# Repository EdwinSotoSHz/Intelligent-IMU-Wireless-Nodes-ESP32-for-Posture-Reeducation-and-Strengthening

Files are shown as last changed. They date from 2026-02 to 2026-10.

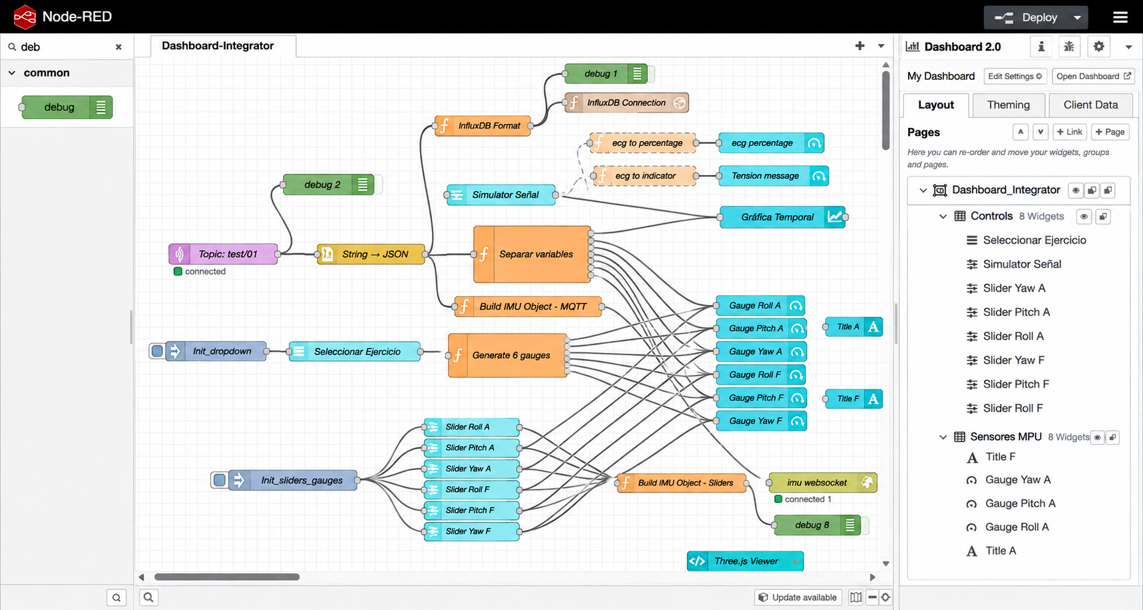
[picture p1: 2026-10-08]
docs/assets/img/nodered_panel.png

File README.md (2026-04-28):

<div align="center">










</div>

# RehabiNodes

> Sistema de monitoreo inalámbrico basado en sensores y tecnologías open source que, al combinar unidades de medición inercial (IMU) y sensores de electromiografía/ECG, es capaz de capturar, procesar y visualizar en tiempo real el movimiento y la actividad muscular del brazo y antebrazo, con el propósito de mejorar la precisión en la ejecución de ejercicios y optimizar los procesos de rehabilitación física domiciliaria.

---

## 📖 Descripción

**RehabiNodes** es un prototipo de plataforma de rehabilitación física domiciliaria orientada a la recuperación funcional del brazo y antebrazo tras una lesión.

El sistema integra dos fuentes de datos complementarias:

- **Nodos IMU inalámbricos** (ESP32 + MPU9250) que miden la orientación y el movimiento en los 3 ejes del brazo y el antebrazo, permitiendo evaluar el rango articular y la calidad de ejecución de cada ejercicio.
- **Sensor ECG/EMG** (AD8232) embebido en el nodo de brazo, que captura la señal eléctrica muscular para detectar compensaciones, fatiga y nivel de activación durante la sesión.

Toda la información se visualiza en tiempo real a través de un panel centralizado (Node Red) que incluye un **modelo 3D interactivo simple** del brazo (Three.js), **estimación de ángulos y compensaciones por visión artificial** (MediaPipe), y **gráficas históricas de señales** (Grafana + InfluxDB).

---

## 🎯 Objetivo

Diseñar e implementar un sistema portátil e inalámbrico para la medición y análisis del movimiento del brazo y antebrazo, con el fin de:

- Guiar al paciente durante ejercicios de **movilidad motora**, **rango articular** y **estiramiento**.
- Apoyar la **readaptación progresiva y segura** después de una lesión, reintegrando al paciente a sus rutinas de forma controlada.
- Visualizar **compensaciones posturales** y movimientos inadecuados mediante estimación de ángulos y posición.
- Proporcionar al clínico **métricas** (rango de movimiento, actividad muscular, simetría) para el seguimiento terapéutico.

### Metas técnicas

- **Hardware sensorial:** Integrar y calibrar IMUs (MPU9250) en nodos de brazo y antebrazo para capturar ángulos de rotación y aceleración en 3 ejes.
- **Procesamiento de señales:** Filtrar y procesar datos brutos de sensores para interpretar movimientos y detectar compensaciones musculares inadecuadas.
- **Interfaz de usuario (Dashboard):** Desarrollar un panel en Node-RED con visualización en tiempo real (Three.js + MediaPipe) y seguimiento histórico (Grafana + InfluxDB).

---

## 🔬 Alcance del Prototipo

Este prototipo se centra exclusivamente en la rehabilitación del **brazo y antebrazo**. Las capacidades actuales son:

<table border="1" cellspacing="0" cellpadding="6">
  <thead>
    <tr>
      <th>Capacidad</th>
      <th>Implementación</th>
    </tr>
  </thead>
  <tbody>
    <tr>
      <td>Medición de movimiento en 3 ejes</td>
      <td>IMU MPU9250 en nodo de brazo y antebrazo</td>
    </tr>
    <tr>
      <td>Señal ECG / actividad muscular</td>
      <td>AD8232 en nodo de brazo</td>
    </tr>
    <tr>
      <td>Estimación de movimientos articulares</td>
      <td>Visualización de landmarks de MediaPipe</td>
    </tr>
    <tr>
      <td>Apoyo visual para la identificación de compensaciones</td>
      <td>MediaPipe y cálculo de ángulos</td>
    </tr>
    <tr>
      <td>Visualización 3D simple en tiempo real</td>
      <td>Three.js actualizado por WebSocket</td>
    </tr>
    <tr>
      <td>Almacenamiento y análisis histórico</td>
      <td>InfluxDB + Grafana</td>
    </tr>
    <tr>
      <td>Panel de control clínico</td>
      <td>Node-RED con iframes al servidor Node.js</td>
    </tr>
    <tr>
      <td>Comunicación inalámbrica de largo alcance</td>
      <td>ESP-NOW + LoRa + GPRS/4G + MQTT</td>
    </tr>
  </tbody>
</table>

> ⚠️ El análisis de postura corporal completa (cuerpo, cadera, rodillas y manos) **es compleentario** de este prototipo y podrá escalarse en versiones futuras.

---

## 🏗️ Arquitectura del Sistema y Flujo de Datos

```mermaid

graph LR
    %% ===== ESTILOS BASADOS EN LOGOS OFICIALES (Borde fuerte / Fondo suave) =====
    classDef hardware fill:#f5f5f5,stroke:#9e9e9e,stroke-width:2px,color:#212121
    classDef master fill:#e3f2fd,stroke:#2196f3,stroke-width:2px,color:#0d47a1
    classDef gateway fill:#e8f5e9,stroke:#4caf50,stroke-width:2px,color:#1b5e20
    classDef cloud fill:#ede7f6,stroke:#673ab7,stroke-width:2px,color:#311b92
    classDef docker fill:#e1f5fe,stroke:#0db7ed,stroke-width:2px,color:#006064
    classDef nodered fill:#ffebee,stroke:#8f0000,stroke-width:2px,color:#8f0000
    classDef influx fill:#e1f5fe,stroke:#00a3e0,stroke-width:2px,color:#003d5b
    classDef grafana fill:#fff3e0,stroke:#f05a28,stroke-width:2px,color:#bf360c
    classDef nodejs fill:#f1f8e9,stroke:#68a063,stroke-width:2px,color:#1b5e20

    subgraph Perifericos ["Nodos Sensores"]
        A1["💪 <b>Arm Node</b><br/>ESP32-C3 + MPU9250 + AD8232"]
        A2["💪 <b>Forearm Node</b><br/>ESP32-C3 + MPU9250"]
    end

    B1["🧠 <b>Master Node</b><br/>ESP32 + LoRa SX1278"]
    
    C1["📡 <b>Gateway</b><br/>LILYGO T70g"]

    D1{{"☁️ <b>EMQX MQTT Broker</b>"}}

    subgraph DockerContainer ["🐋 Docker Compose"]
        E1["📉 <b>Node-RED</b>"]
        E2[("🗄️ InfluxDB")]
        E3["📈 <b>Grafana</b>"]
        
        subgraph NodeJS ["⚙️ Servidor Node.js"]
            E4["📷 MediaPipe<br/>(Pose Estimation)"]
            E5["🧊 Three.js<br/>(3D Render)"]
        end
    end

    %% Conexiones y Protocolos
    A1 & A2 -- "ESP-NOW" --> B1
    B1 -- "LoRa" --> C1
    C1 -- "GPRS/4G LTE" --> D1
    D1 --> E1
    
    %% Conexiones de visualización e integración
    E1 -- "iframe" --> E5
    E1 -- "iframe" --> E4
    E1 <-->|"WebSocket"| E5
    E1 -->|"Flux"| E2
    E2 -->|"Flux"| E3

    %% Aplicación de Estilos
    class A1,A2 hardware
    class B1 master
    class C1 gateway
    class D1 cloud
    class DockerContainer docker
    class E1 nodered
    class E2 influx
    class E3 grafana
    class E4,E5 nodejs
    
```

<table border="1" cellspacing="0" cellpadding="8">
  <thead>
    <tr>
      <th>Componente</th>
      <th>Rol funcional en el flujo</th>
    </tr>
  </thead>
  <tbody>
    <tr>
      <td><strong>node_arm</strong><br/><small>ESP32-C3 + MPU9250 + AD8232</small></td>
      <td>Captura IMU (orientación) y ECG del brazo. Transmite por ESP‑NOW al maestro.</td>
    </tr>
    <tr>
      <td><strong>node_forearm</strong><br/><small>ESP32-C3 + GY‑91 (MPU9250 + BMP280)</small></td>
      <td>Captura IMU del antebrazo. Transmite por ESP‑NOW al maestro. (BMP280 no usado activamente)</td>
    </tr>
    <tr>
      <td><strong>master_node</strong><br/><small>ESP32 + LoRa Ra‑02 SX1278</small></td>
      <td>Agrega datos de ambos nodos vía ESP‑NOW y los retransmite por LoRa hacia el gateway.</td>
    </tr>
    <tr>
      <td><strong>gateway</strong><br/><small>LILYGO T‑SIM7070G + LoRa</small></td>
      <td>Recibe el paquete LoRa y lo publica al broker MQTT usando GPRS/4G LTE.</td>
    </tr>
    <tr>
      <td><strong>Broker MQTT (EMQX)</strong></td>
      <td>Punto de entrada único al backend. Desacopla la capa de hardware del procesamiento.</td>
    </tr>
    <tr>
      <td><strong>Node‑RED</strong></td>
      <td>Hub de integración: suscribe MQTT, normaliza datos, los envía a InfluxDB y al servidor web (vía WebSocket/HTTP).</td>
    </tr>
    <tr>
      <td><strong>ExpressJS (servidor Node.js)</strong></td>
      <td>Sirve las interfaces de MediaPipe y Three.js. Gestiona el WebSocket que actualiza el modelo 3D.</td>
    </tr>
    <tr>
      <td><strong>Three.js</strong></td>
      <td>Renderiza el modelo 3D del brazo/antebrazo en el navegador, actualizado en tiempo real por WebSocket.</td>
    </tr>
    <tr>
      <td><strong>MediaPipe JS</strong></td>
      <td>Estima ángulos articulares y detecta compensaciones motoras mediante visión por computadora (landmarks).</td>
    </tr>
    <tr>
      <td><strong>InfluxDB</strong></td>
      <td>Almacena series temporales de IMU y ECG para análisis histórico y trazabilidad de sesiones.</td>
    </tr>
    <tr>
      <td><strong>Grafana</strong></td>
      <td>Dashboards de evolución clínica: rangos de movimiento, actividad muscular, simetría, alertas.</td>
    </tr>
  </tbody>
</table>

---

## 📡 Protocolos de Comunicación

<table>
  <thead>
    <tr>
      <th>Protocolo</th>
      <th>Función en el proyecto</th>
      <th>Descripción breve</th>
    </tr>
  </thead>
  <tbody>
    <tr>
      <td><strong>ESP-NOW</strong></td>
      <td>Comunicación entre nodos (brazo/antebrazo) y nodo maestro</td>
      <td>Protocolo peer-to-peer sin conexión WiFi de Espressif, baja latencia</td>
    </tr>
    <tr>
      <td><strong>LoRa (SX1278)</strong></td>
      <td>Enlace inalámbrico nodo maestro → gateway</td>
      <td>Modulación de espectro ensanchado para largo alcance y bajo consumo</td>
    </tr>
    <tr>
      <td><strong>GPRS / 4G LTE</strong></td>
      <td>Gateway → Broker MQTT (transmisión celular)</td>
      <td>Red móvil de datos para enviar información a la nube</td>
    </tr>
    <tr>
      <td><strong>MQTT</strong></td>
      <td>Broker ↔ Node-RED y publicaciones desde gateway/mocks</td>
      <td>Protocolo ligero de publicación/suscripción sobre TCP/IP</td>
    </tr>
    <tr>
      <td><strong>WebSocket</strong></td>
      <td>Servidor ExpressJS ↔ Three.js (modelo 3D)</td>
      <td>Canal bidireccional full-duplex sobre una única conexión TCP</td>
    </tr>
    <tr>
      <td><strong>HTTP / HTTPS</strong></td>
      <td>Servidor ExpressJS entrega archivos estáticos y rutas REST</td>
      <td>Protocolo cliente-servidor para transferencia de hipertexto</td>
    </tr>
    <tr>
      <td><strong>I²C (I2C)</strong></td>
      <td>Comunicación ESP32-C3 ↔ MPU9250 y ESP32-C3 ↔ AD8232</td>
      <td>Bus serie síncrono de dos hilos (SDA/SCL) para sensores</td>
    </tr>
    <tr>
      <td><strong>SPI</strong></td>
      <td>ESP32 ↔ Módulo LoRa SX1278 (nodo maestro)</td>
      <td>Bus serie síncrono full-duplex con selección de esclavo</td>
    </tr>
    <tr>
      <td><strong>UART (Serial)</strong></td>
      <td>Depuración (Serial Monitor) y posible comunicación entre módulos</td>
      <td>Comunicación asíncrona simple con TX/RX</td>
    </tr>
    <tr>
      <td><strong>USB (CDC)</strong></td>
      <td>Carga de firmware y monitoreo serial en ESP32-C3/ESP32</td>
      <td>USB nativo o serial-over-USB para programación y debug</td>
    </tr>
  </tbody>
</table>

### Hardware de Sensado y Adquisición

<table>
  <thead>
    <tr>
      <th>Componente</th>
      <th>Rol</th>
      <th>Notas</th>
    </tr>
  </thead>
  <tbody>
    <tr>
      <td><strong>ESP32-C3 Super Mini</strong></td>
      <td>MCU de los nodos de brazo y antebrazo</td>
      <td>Bajo consumo, formato compacto</td>
    </tr>
    <tr>
      <td><strong>ESP32</strong></td>
      <td>MCU del nodo maestro</td>
      <td>Mayor cantidad de pines para LoRa y periféricos</td>
    </tr>
    <tr>
      <td><strong>LILYGO T-SIM7070G</strong></td>
      <td>Gateway con conectividad celular</td>
      <td>GPRS/4G LTE integrado + interfaz para LoRa</td>
    </tr>
    <tr>
      <td><strong>MPU9250</strong></td>
      <td>IMU 9-DOF (brazo)</td>
      <td>Acelerómetro + giroscopio + magnetómetro</td>
    </tr>
    <tr>
      <td><strong>MPU9250</strong></td>
      <td>IMU + barómetro (antebrazo)</td>
      <td>Integra MPU9250 y BMP280 (altitud/temperatura)</td>
    </tr>
    <tr>
      <td><strong>AD8232</strong></td>
      <td>Sensor ECG / EMG (brazo)</td>
      <td>Captura de señal eléctrica muscular</td>
    </tr>
    <tr>
      <td><strong>Ra-02 SX1278</strong></td>
      <td>Módulo LoRa</td>
      <td>Enlace nodo maestro ↔ gateway. Bajo consumo, largo alcance</td>
    </tr>
  </tbody>
</table>

### Backend e Infraestructura

<table>
  <thead>
    <tr>
      <th>Tecnología</th>
      <th>Rol</th>
    </tr>
  </thead>
  <tbody>
    <tr>
      <td><strong>Node.js + ExpressJS</strong></td>
      <td>Servidor HTTP, WebSocket y archivos estáticos</td>
    </tr>
    <tr>
      <td><strong>InfluxDB</strong></td>
      <td>Base de datos de series temporales (IMU, ECG)</td>
    </tr>
    <tr>
      <td><strong>Docker + Docker Compose</strong></td>
      <td>Contenerización de todo el stack</td>
    </tr>
  </tbody>
</table>

### Visualización en Tiempo Real

<table>
  <thead>
    <tr>
      <th>Tecnología</th>
      <th>Rol</th>
    </tr>
  </thead>
  <tbody>
    <tr>
      <td><strong>Node-RED</strong></td>
      <td>Dashboard principal, integración MQTT, iframes y WebSocket</td>
    </tr>
    <tr>
      <td><strong>Three.js</strong></td>
      <td>Modelo 3D del brazo/antebrazo actualizado por WebSocket</td>
    </tr>
    <tr>
      <td><strong>MediaPipe JS</strong></td>
      <td>Estimación de ángulos articulares y detección de compensaciones por cámara</td>
    </tr>
    <tr>
      <td><strong>Grafana</strong></td>
      <td>Dashboards históricos y alertas clínicas</td>
    </tr>
  </tbody>
</table>

> [!NOTE]  
> Todas las tecnologías listadas son **open source** o con **licencia de uso libre**.

---

## 📁 Estructura del Repositorio

```bash
📁 RehabiNodes/
├── 📁 3D-Model/           # Modelos STL de carcasas para impresión 3D
├── 📁 Project/            # Desarrollo completo del sistema
│   ├── 📁 IoT/            # Firmware ESP32 (nodos, gateway y maestro)
│   ├── 📁 webservices/    # Backend Node.js + visualización (Three.js, MediaPipe)
│   ├── 📁 mocks/          # Simulación de datos sin hardware físico
│   └── 📁 Dashboard/      # Exportaciones de dashboards (Node-RED / Grafana / InfluxDB)
├── 📁 Tests/              # Pruebas y experimentación por subsistema
├── 📁 Wiring-Diagrams/    # Diagramas eléctricos y de conexión
├── 📁 Releases/           # Despliegue con Docker Compose
└── README.md
```

<details>
<summary>📂 Ver estructura interna por sección</summary>

### 📁 IoT
```bash
📁 IoT/
├── 📁 gateway/         # Gateway LILYGO (LoRa → MQTT vía red celular)
├── 📁 master_node/     # Nodo maestro (agregación ESP-NOW → LoRa)
├── 📁 node_arm/        # Nodo de brazo (IMU + ECG)
└── 📁 node_forearm/    # Nodo de antebrazo (IMU)
```

### 📁 webservices
```bash
📁 webservices/
├── 📁 MediaPipe/       # Procesamiento local de visión (landmarks y ángulos)
├── 📁 Threejs/         # Modelo 3D actualizado vía WebSocket
└── 📁 server/          # Servidor Express (HTTP + WebSocket)
```

### 📁 mocks
```bash
📁 mocks/
├── 📁 master_node_direct_mqtt/  # Simulación: envío directo a MQTT sin LoRa/gateway
├── 📁 mqtt/                     # Scripts, certificados y pruebas de broker MQTT
├── 📁 simulated_node_arm/       # Nodo de brazo con datos simulados (IMU + ECG)
└── 📁 simulated_node_forearm/   # Nodo de antebrazo con datos simulados (IMU)
```

### 📁 Tests
```bash
📁 Tests/
├── 📁 Communication-Unused/  # Pruebas de LoRa, MQTT, ESP-NOW, WiFi (no integradas)
├── 📁 MPU/                   # Calibración y pruebas del MPU9250
├── 📁 node-red/              # Ejemplos de dashboards y flujos
├── 📁 test-ecg/              # Pruebas del sensor AD8232
├── 📁 test-mediapipe/        # Prototipos con MediaPipe JS
├── 📁 test-threejs/          # Prototipos Three.js + WebSocket
└── 📁 deprecated/            # Experimentos descartados
```

### 📁 Wiring-Diagrams
```bash
📁 Wiring-Diagrams/
├── Connections-ESP32C3-MPU9250-AD8232.svg  # Prototipo IoT
├── Connections-ESP32-LoRaSX1278.svg        # Conexiones con el modulo LoRa
└── Connections-Lilygo7070g-LoRaSX1278.svg     # LILYGO + LoRa
```

### 📁 Releases
```bash
📁 Releases/
├── 📁 nodered/            # Imagen personalizada de Node-RED
├── backup_full.tar.gz     # Backup de volúmenes (InfluxDB, Grafana, Node-RED)
└── docker-compose.yml     # Orquestación completa del sistema
```

</details>

## 🔌 Diagramas de Conexión

Los diagramas de conexión física se encuentran en [`Project/Wiring-Diagrams/`](./Project/Wiring-Diagrams/).

| Diagrama | Descripción |
|---|---|
| [`Connections-ESP32C3-MPU9250-AD8232.svg`](./Project/Wiring-Diagrams/Connections-ESP32C3-MPU9250-AD8232.fzz.svg) | Conexión del nodo de brazo: ESP32-C3 Super Mini + MPU9250 (IMU) + AD8232 (ECG/EMG) |
| [`Connections-ESP32-LoRaSX1278.svg`](./Project/Wiring-Diagrams/Connections-ESP32-LoRaSX1278.svg) | Conexión del nodo maestro: ESP32 + módulo LoRa Ra-02 SX1278 |
| [`Connections-Lilygo7070g-LoRaSX1278.svg`](./Project/Wiring-Diagrams/Connections-Lilygo7070g-LoRaSX1278.svg) | Conexión del gateway: LILYGO T-SIM7070G + módulo LoRa Ra-02 SX1278 |

---

# 🧠 Intelligent IMU Wireless Nodes - Docker Setup

## 📋 Descripción

Este proyecto utiliza contenedores Docker para ejecutar:

* Node-RED (procesamiento de datos y MQTT)
* WebServices (backend)
* InfluxDB (base de datos time-series)
* Grafana (visualización)

Incluye persistencia mediante volúmenes y soporte para backup/restore completo.

---

## 🚀 Comandos Básicos

### 🔹 Volúmenes

```bash
docker volume ls                 # Listar volúmenes
docker volume inspect <name>    # Ver detalles de un volumen
docker volume rm <name>         # Eliminar volumen
```

---

### 🔹 Docker Compose

```bash
docker-compose up -d --build    # Construir y levantar servicios
docker-compose down             # Detener y eliminar contenedores
```

---

## 🐳 Acceso a Contenedores

### Entrar a Node-RED

```bash
docker exec -it nodered bash
```

---

## 💾 Backup de Volúmenes

Exporta todos los datos (InfluxDB, Grafana, Node-RED):

```powershell
docker run --rm `
-v releases_influxdb-data:/influxdb-data `
-v releases_influxdb-config:/influxdb-config `
-v releases_grafana-data:/grafana-data `
-v releases_node-red-data:/node-red-data `
-v ${PWD}:/backup `
alpine `
tar czf /backup/backup_full.tar.gz `
/influxdb-data /influxdb-config /grafana-data /node-red-data
```

Archivo generado:

```text
backup_full.tar.gz
```

---

## 🧹 Eliminar Volúmenes (Reset completo)

```bash
docker-compose down

docker volume rm releases_influxdb-data
docker volume rm releases_influxdb-config
docker volume rm releases_grafana-data
docker volume rm releases_node-red-data

docker volume ls
```

---

## ♻️ Restaurar Backup

```powershell
docker run --rm `
-v releases_influxdb-data:/influxdb-data `
-v releases_influxdb-config:/influxdb-config `
-v releases_grafana-data:/grafana-data `
-v releases_node-red-data:/node-red-data `
-v ${PWD}:/backup `
alpine `
tar xzf /backup/backup_full.tar.gz -C /
```

---

## 🌐 Accesos

| Servicio | URL |
| --- | --- |
| Node-RED | [http://localhost:1880/](http://localhost:1880/) |
| WebServices | [http://localhost:3000/](http://localhost:3000/) |
| InfluxDB | [http://localhost:8086/](http://localhost:8086/) |
| Grafana | [http://localhost:3001/](http://localhost:3001/) |

---

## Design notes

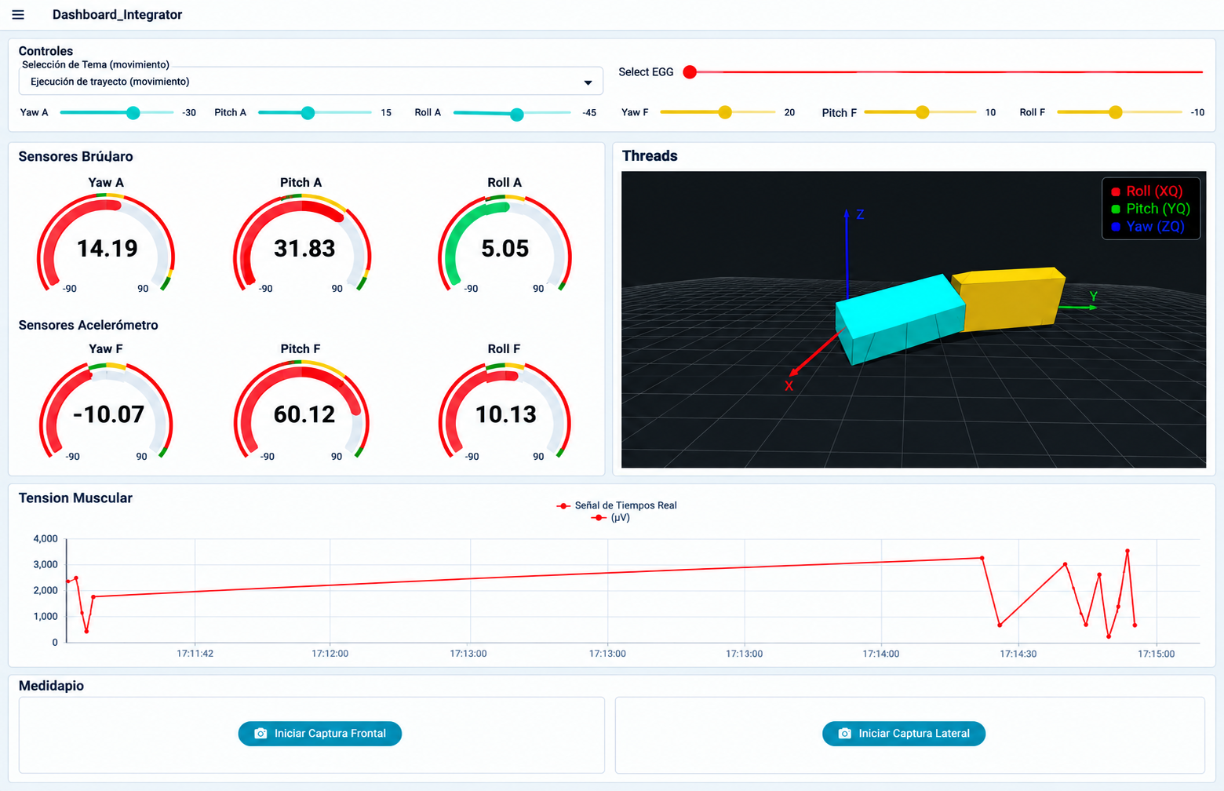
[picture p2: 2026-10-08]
docs/assets/img/mediapipe_view.png

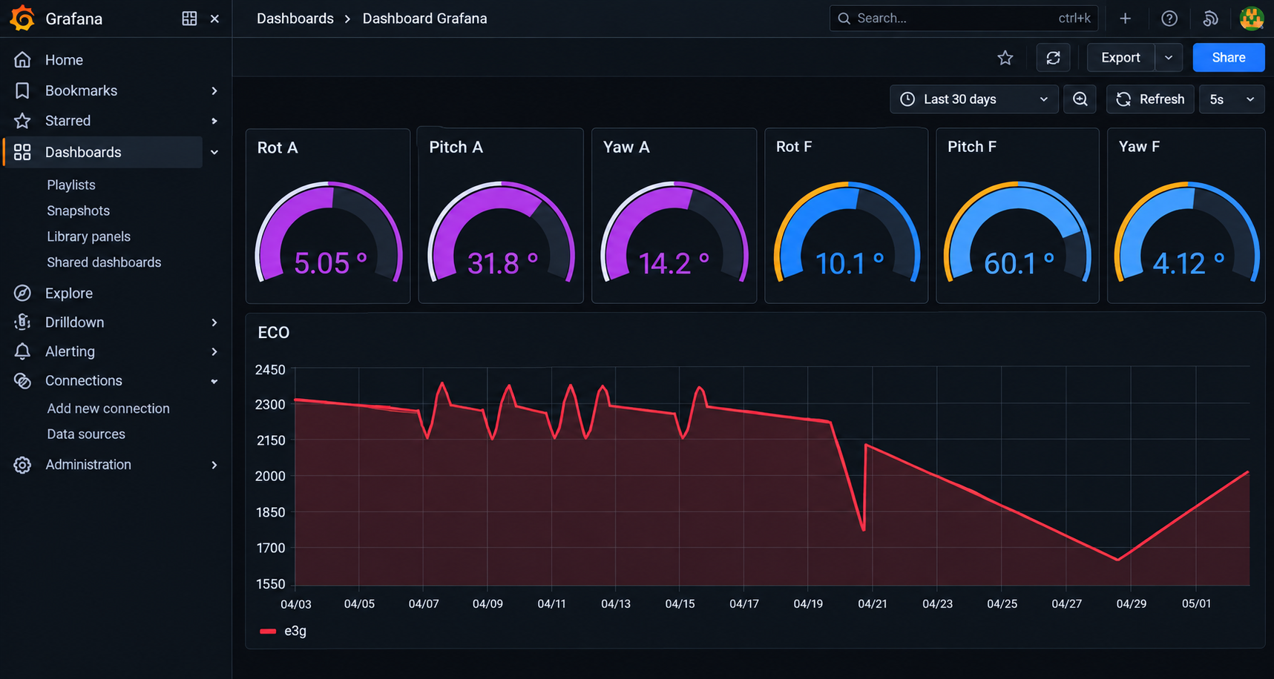
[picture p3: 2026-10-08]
docs/assets/img/grafana_dashboard.png

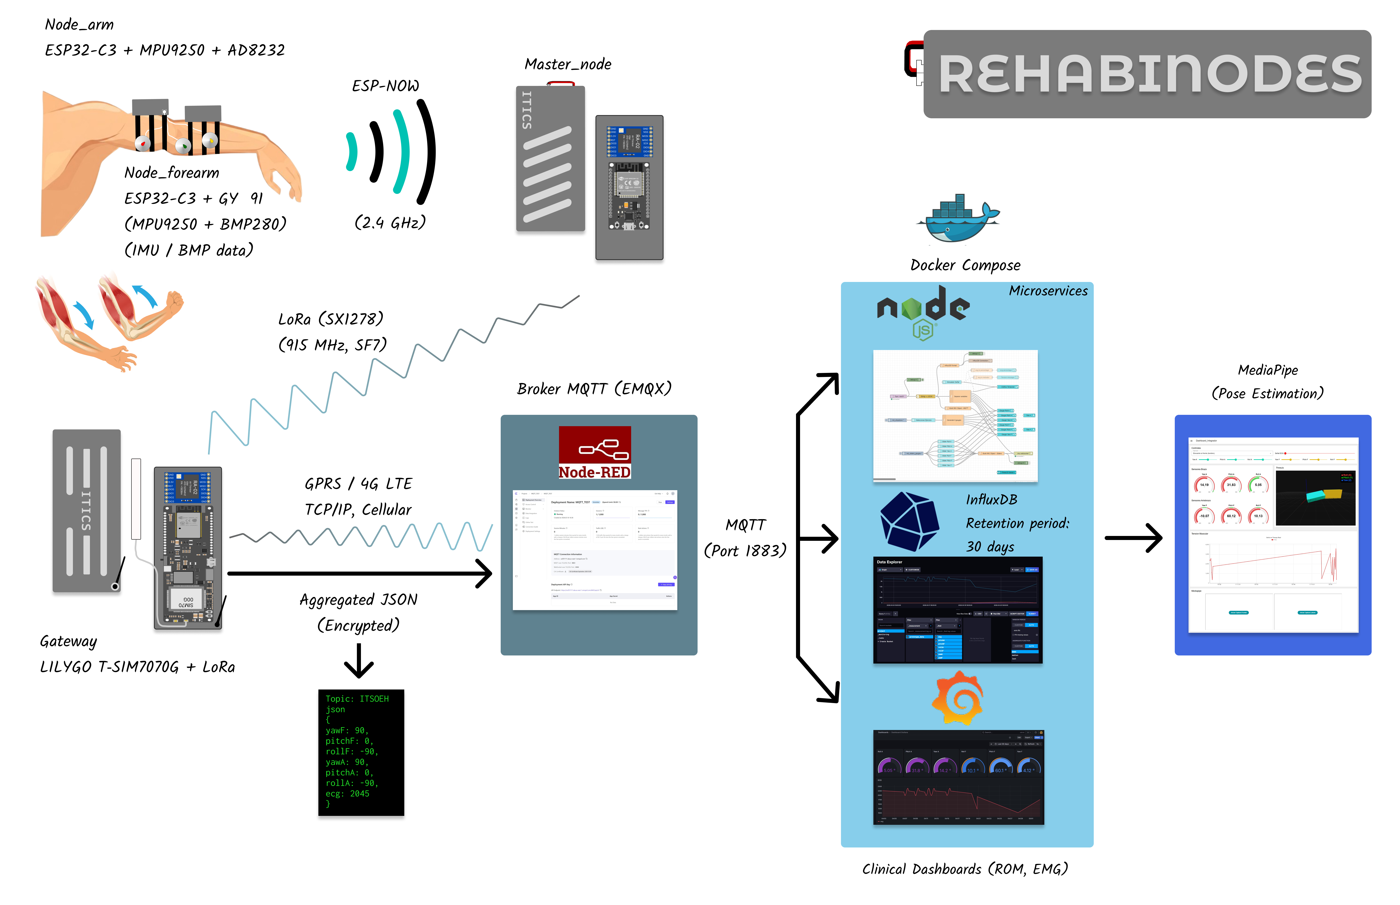
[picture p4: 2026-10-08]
docs/assets/img/RehabiNodes_Arquitectura.png

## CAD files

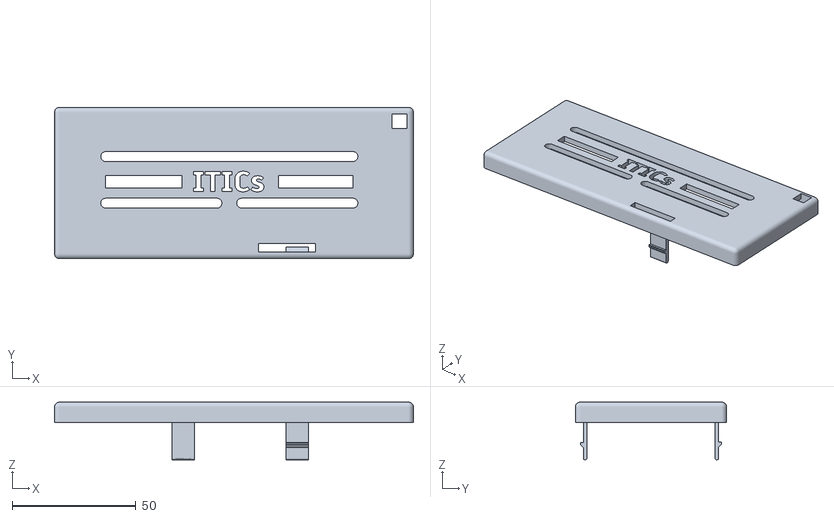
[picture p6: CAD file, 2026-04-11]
3D-Model/TopCaseLIligo.stl
145.2 x 61.2 x 23.4

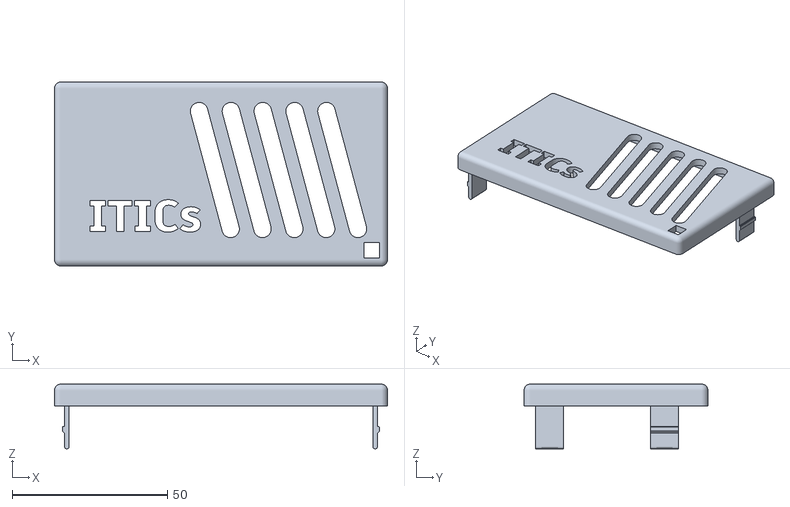
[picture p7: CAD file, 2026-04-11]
3D-Model/TopCaseLoRa.stl
107.2 x 59.2 x 20.9

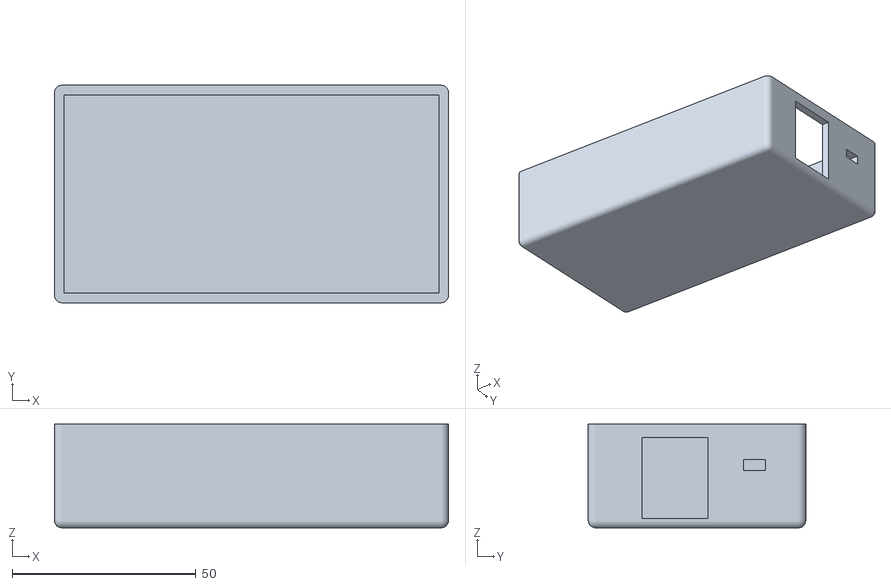
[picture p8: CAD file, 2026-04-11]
3D-Model/BottomCaseLoRa.stl
107.2 x 59.2 x 28.2

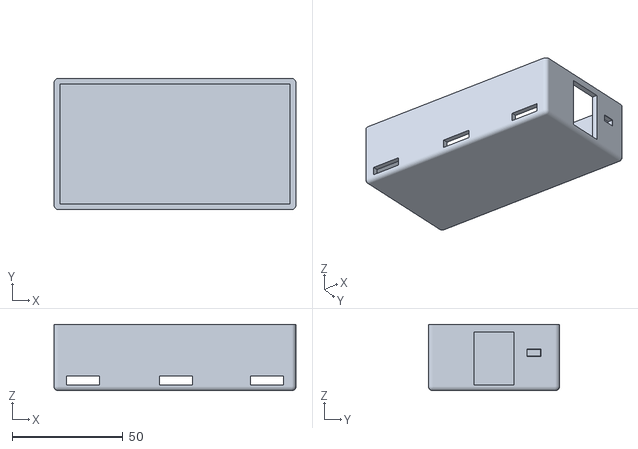
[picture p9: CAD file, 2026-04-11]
3D-Model/BottomCase.stl
109.2 x 59.2 x 30.0

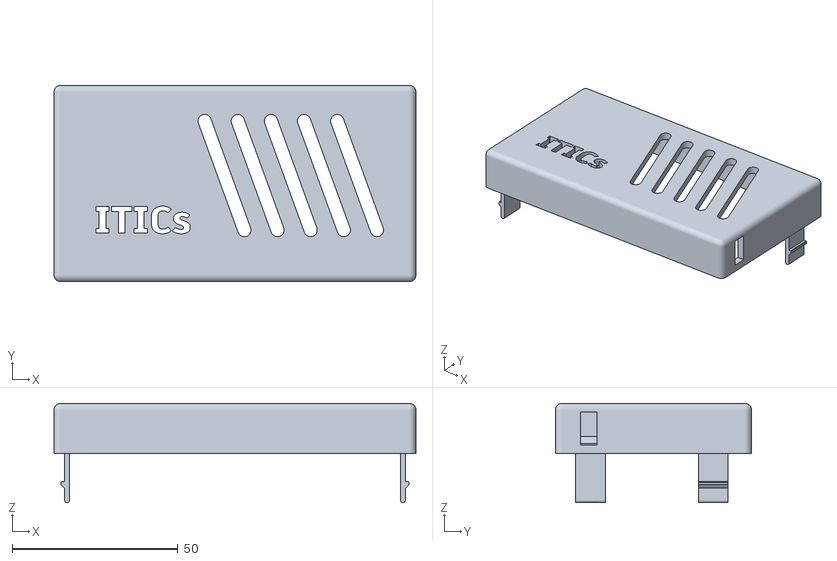
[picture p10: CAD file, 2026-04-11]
3D-Model/TopCase.stl
109.2 x 59.2 x 30.0

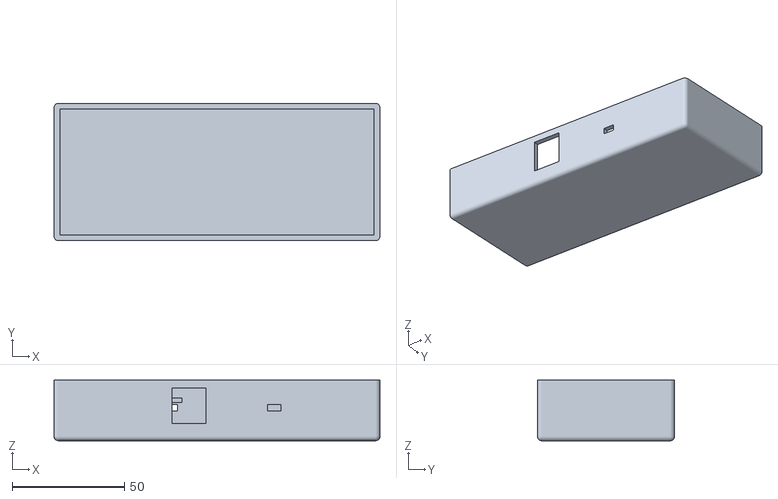
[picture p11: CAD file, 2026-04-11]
3D-Model/BottomCaseLiligo.stl
145.2 x 61.2 x 27.0

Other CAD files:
3D-Model/CaseLiligo.f3d
3D-Model/CaseLoRa.f3d
3D-Model/SesnsorsCase.f3d
docs/assets/PrototypeView.blend

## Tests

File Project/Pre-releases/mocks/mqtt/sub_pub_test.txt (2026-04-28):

mosquitto_sub -h oc051111.ala.us-east-1.emqxsl.com -p 8883 -t test01 -u "edpi" -P "edpi" --cafile "C:\Users\edwin\OneDrive\Documentos\para-repo\Intelligent-IMU-Wireless-Nodes-ESP32-for-Posture-Reeducation-and-Strengthening\Project\Pre-releases\mocks\mqtt\emqxsl-ca.crt"

mosquitto_pub -h oc051111.ala.us-east-1.emqxsl.com -p 8883 -t test01 -m "Hola EMQX" -u "edpi" -P "edpi" --cafile "C:\Users\edwin\OneDrive\Documentos\para-repo\Intelligent-IMU-Wireless-Nodes-ESP32-for-Posture-Reeducation-and-Strengthening\Project\Pre-releases\mocks\mqtt\emqxsl-ca.crt"

mosquitto_pub -h oc051111.ala.us-east-1.emqxsl.com -p 8883 -t test01 -f "C:\Users\edwin\OneDrive\Documentos\para-repo\Intelligent-IMU-Wireless-Nodes-ESP32-for-Posture-Reeducation-and-Strengthening\Project\Pre-releases\mocks\mqtt\msg-template.json" -u "edpi" -P "edpi" --cafile "C:\Users\edwin\OneDrive\Documentos\para-repo\Intelligent-IMU-Wireless-Nodes-ESP32-for-Posture-Reeducation-and-Strengthening\Project\Pre-releases\mocks\mqtt\emqxsl-ca.crt"

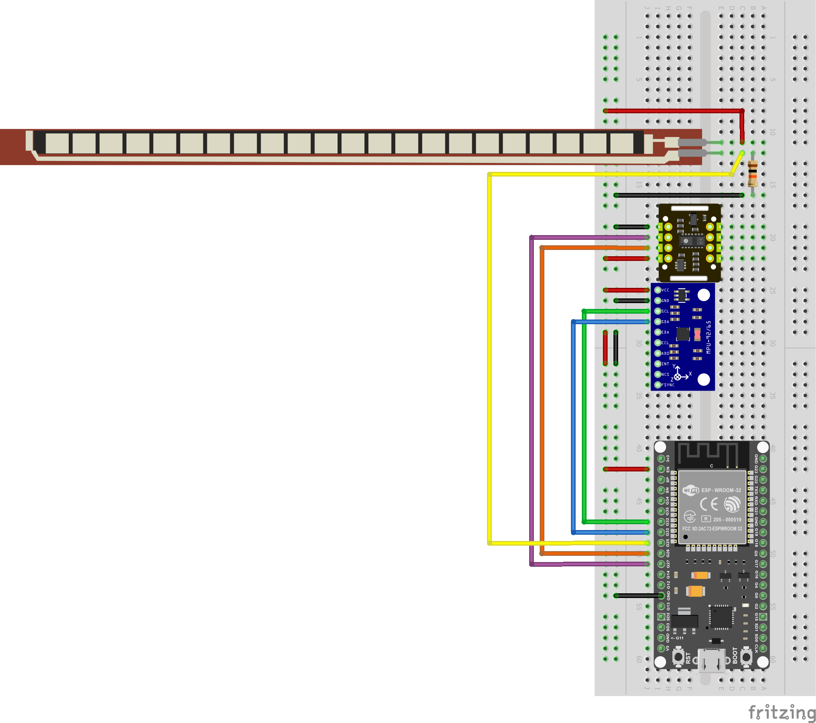
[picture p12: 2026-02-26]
Sensors/Wiring-Diagrams/TEST-ESP32-FLEX-MPU-MAX.png

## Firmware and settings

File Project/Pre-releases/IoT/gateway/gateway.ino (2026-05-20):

// mosquitto_sub -h oc051111.ala.us-east-1.emqxsl.com -p 8883 -t test01 -u "edpi" -P "edpi" --cafile "C:\Users\edwin\OneDrive\Documentos\para-repo\Intelligent-IMU-Wireless-Nodes-ESP32-for-Posture-Reeducation-and-Strengthening\Proyect\Pre-releases\mocks\mqtt\emqxsl-ca.crt"
// ESP32 38 PINS LILYGO - GATEWAY LoRa a MQTT sobre RED CELULAR con fallback WiFi
// Integración: Recibe datos por LoRa y los reenvía por MQTT vía LTE/NB-IoT o WiFi

// ==========================================
// CONFIGURACIÓN LORA (RECEPTOR)
// ==========================================
#include <LoRa.h>
#include <WiFi.h>
#include <WiFiClientSecure.h>  // ← LIBRERÍA AGREGADA PARA TLS EN WiFi

// pines RECEPTOR LORA
const int loraRST = 21;
const int loraDI0 = 22;
const int loraNSS = 5;
const int loraMOSI = 23;
const int loraMISO = 19;
const int loraSCK = 18;

int SyncWord = 0x22;

// ==========================================
// PROTOCOLO DE FRAMES (Igual que HeltecV3)
// ==========================================
byte dir_local = 0xB2; // MI DIRECCIÓN (Debe coincidir con destino del sender)

// Variables para "desempaquetar"
byte dir_envio     = 0; 
byte dir_remite    = 0; 
byte paqRcb_ID     = 0;
byte paqRcb_Estado = 0; 

// Estructura del payload (debe coincidir con el transmisor)
typedef struct struct_message {
    float roll_f, pitch_f, yaw_f;
    int ecg;
    float roll_a, pitch_a, yaw_a;
} struct_message;

// ==========================================
// CONFIGURACIÓN MÓDEM CELULAR (SIM7070)
// ==========================================
#define TINY_GSM_MODEM_SIM7070

#include <TinyGsmClient.h>
#include <PubSubClient.h>

// --- CONFIGURACIÓN DE ACCESO A LA RED ---
const char apn[]      = "internet.itelcel.com"; 
const char gprsUser[] = ""; 
const char gprsPass[] = "";

// --- MQTT CON TLS/SSL ---
const char* broker = "oc051111.ala.us-east-1.emqxsl.com";
const char* topicPublish = "test01";
const int   port = 8883;
const char* mqtt_user = "edpi";
const char* mqtt_password = "edpi";

// --- CERTIFICADO CA ---
const char* ca_cert = \
"-----BEGIN CERTIFICATE-----\n" \
"MIIDjjCCAnagAwIBAgIQAzrx5qcRqaC7KGSxHQn65TANBgkqhkiG9w0BAQsFADBh\n" \
"MQswCQYDVQQGEwJVUzEVMBMGA1UEChMMRGlnaUNlcnQgSW5jMRkwFwYDVQQLExB3\n" \
"d3cuZGlnaWNlcnQuY29tMSAwHgYDVQQDExdEaWdpQ2VydCBHbG9iYWwgUm9vdCBH\n" \
"MjAeFw0xMzA4MDExMjAwMDBaFw0zODAxMTUxMjAwMDBaMGExCzAJBgNVBAYTAlVT\n" \
"MRUwEwYDVQQKEwxEaWdpQ2VydCBJbmMxGTAXBgNVBAsTEHd3dy5kaWdpY2VydC5j\n" \
"b20xIDAeBgNVBAMTF0RpZ2lDZXJ0IEdsb2JhbCBSb290IEcyMIIBIjANBgkqhkiG\n" \
"9w0BAQEFAAOCAQ8AMIIBCgKCAQEAuzfNNNx7a8myaJCtSnX/RrohCgiN9RlUyfuI\n" \
"2/Ou8jqJkTx65qsGGmvPrC3oXgkkRLpimn7Wo6h+4FR1IAWsULecYxpsMNzaHxmx\n" \
"1x7e/dfgy5SDN67sH0NO3Xss0r0upS/kqbitOtSZpLYl6ZtrAGCSYP9PIUkY92eQ\n" \
"q2EGnI/yuum06ZIya7XzV+hdG82MHauVBJVJ8zUtluNJbd134/tJS7SsVQepj5Wz\n" \
"tCO7TG1F8PapspUwtP1MVYwnSlcUfIKdzXOS0xZKBgyMUNGPHgm+F6HmIcr9g+UQ\n" \
"vIOlCsRnKPZzFBQ9RnbDhxSJITRNrw9FDKZJobq7nMWxM4MphQIDAQABo0IwQDAP\n" \
"BgNVHRMBAf8EBTADAQH/MA4GA1UdDwEB/wQEAwIBhjAdBgNVHQ4EFgQUTiJUIBiV\n" \
"5uNu5g/6+rkS7QYXjzkwDQYJKoZIhvcNAQELBQADggEBAGBnKJRvDkhj6zHd6mcY\n" \
"1Yl9PMWLSn/pvtsrF9+wX3N3KjITOYFnQoQj8kVnNeyIv/iPsGEMNKSuIEyExtv4\n" \
"NeF22d+mQrvHRAiGfzZ0JFrabA0UWTW98kndth/Jsw1HKj2ZL7tcu7XUIOGZX1NG\n" \
"Fdtom/DzMNU+MeKNhJ7jitralj41E6Vf8PlwUHBHQRFXGU7Aj64GxJUTFy8bJZ91\n" \
"8rGOmaFvE7FBcf6IKshPECBV1/MUReXgRPTqh5Uykw7+U0b6LJ3/iyK5S9kJRaTe\n" \
"pLiaWN0bfVKfjllDiIGknibVb63dDcY3fe0Dkhvld1927jyNxF1WW6LZZm6zNTfl\n" \
"MrY=\n" \
"-----END CERTIFICATE-----\n";

// --- CONFIGURACIÓN WiFi (FALLBACK) ---
const char* ssid_wifi = "AsusE";
const char* password_wifi = "23011edpi";

// --- PINES MÓDEM ---
#define UART_BAUD   115200
#define PIN_TX      27
#define PIN_RX      26
#define PWR_PIN     4
#define LED_INDICATOR 12

HardwareSerial ModemSerial(1);

TinyGsm modem(ModemSerial);
TinyGsmClientSecure client(modem);
PubSubClient mqtt(client);

// Variables para control de envío MQTT
unsigned long ultimaReconexionMQTT = 0;
const unsigned long intervaloReconexionMQTT = 30000; // 30 segundos

// Variables para control de conexión
enum ConnectionType { CONN_NONE, CONN_LTE, CONN_WIFI };
ConnectionType currentConnection = CONN_NONE;
bool mqttConnected = false;

// Objeto para cliente WiFi secure (se declara global para que persista)
WiFiClientSecure wifiClientSecure;

// ==========================================
// FUNCIONES DEL MÓDEM CELULAR
// ==========================================
void encenderModem() {
  Serial.println("INICIO: Despertando el módulo celular...");
  pinMode(PWR_PIN, OUTPUT);
  digitalWrite(PWR_PIN, LOW);
  delay(100);
  digitalWrite(PWR_PIN, HIGH);
  delay(1000);
  digitalWrite(PWR_PIN, LOW);
  delay(2000);
}

bool inicializarModem() {
  Serial.println("PASO 1: Verificando comunicación AT...");
  if (!modem.restart()) {
    Serial.println("CRÍTICO: El módem no responde.");
    return false;
  }

  Serial.print("PASO 2: Buscando señal de torre celular...");
  if (!modem.waitForNetwork()) {
    Serial.println(" ERROR: Sin cobertura.");
    return false;
  }
  Serial.println(" OK");

  Serial.print("PASO 3: Activando sesión de datos...");
  if (!modem.gprsConnect(apn, gprsUser, gprsPass)) {
    Serial.println(" ERROR APN.");
    return false;
  }

  Serial.print("\nIP LTE: ");
  Serial.println(modem.getLocalIP());
  
  return true;
}

// ==========================================
// FUNCIONES DE CONEXIÓN WiFi
// ==========================================
bool conectarWiFi() {
  Serial.println("\n[WiFi] Intentando conectar a: " + String(ssid_wifi));
  
  WiFi.mode(WIFI_STA);
  WiFi.begin(ssid_wifi, password_wifi);
  
  int intentos = 0;
  while (WiFi.status() != WL_CONNECTED && intentos < 20) {
    delay(500);
    Serial.print(".");
    intentos++;
  }
  
  if (WiFi.status() == WL_CONNECTED) {
    Serial.println("\n[WiFi] Conectado exitosamente!");
    Serial.print("[WiFi] IP: ");
    Serial.println(WiFi.localIP());
    return true;
  } else {
    Serial.println("\n[WiFi] Falló la conexión");
    return false;
  }
}

// ==========================================
// FUNCIONES MQTT (COMUNES)
// ==========================================
void configurarClienteMQTT() {
  if (currentConnection == CONN_WIFI) {
    // Para WiFi, usar cliente WiFi estándar con TLS
    wifiClientSecure.setCACert(ca_cert);
    mqtt.setClient(wifiClientSecure);
  }
  // Para LTE, el cliente ya está configurado como TinyGsmClientSecure
  
  mqtt.setServer(broker, port);
  mqtt.setCallback(NULL);
}

void reconectarMQTT() {
  if (millis() - ultimaReconexionMQTT < intervaloReconexionMQTT && !mqtt.connected()) {
    return;
  }
  
  ultimaReconexionMQTT = millis();
  
  Serial.print("Intentando acceso al Broker MQTT (TLS/SSL) vía ");
  Serial.print(currentConnection == CONN_LTE ? "LTE" : "WiFi");
  Serial.print("...");
  
  String clienteID = "Gateway6B" + String(random(1000, 9999));
  
  if (mqtt.connect(clienteID.c_str(), mqtt_user, mqtt_password)) {
    Serial.println(" CONECTADO.");
    mqttConnected = true;
  } else {
    Serial.print(" FAILED (Code: ");
    Serial.print(mqtt.state());
    Serial.println(")");
    mqttConnected = false;
  }
}

// ==========================================
// FUNCIÓN PRINCIPAL DE CONEXIÓN A INTERNET
// ==========================================
bool conectarInternet() {
  // Intentar primero LTE
  Serial.println("\n[INFO] Intentando conexión vía LTE...");
  encenderModem();
  ModemSerial.begin(UART_BAUD, SERIAL_8N1, PIN_RX, PIN_TX);
  delay(3000);
  
  if (inicializarModem()) {
    currentConnection = CONN_LTE;
    configurarClienteMQTT();
    Serial.println("[INFO] Conexión establecida vía LTE");
    return true;
  }
  
  // Si falla LTE, intentar WiFi
  Serial.println("\n[INFO] LTE falló, intentando WiFi como respaldo...");
  if (conectarWiFi()) {
    currentConnection = CONN_WIFI;
    configurarClienteMQTT();
    Serial.println("[INFO] Conexión establecida vía WiFi");
    return true;
  }
  
  Serial.println("[ERROR] No hay conexión a internet disponible");
  currentConnection = CONN_NONE;
  return false;
}

// ==========================================
// ENVÍO MQTT
// ==========================================
bool enviarMQTT(struct_message &datos) {
  if (currentConnection == CONN_NONE) {
    Serial.println("[MQTT] Sin conexión a internet, reintentando...");
    if (!conectarInternet()) {
      return false;
    }
  }
  
  if (!mqtt.connected()) {
    reconectarMQTT();
    if (!mqtt.connected()) return false;
  }
  
  // -------- CREAR JSON --------
  String payload = "{";
  payload += "\"roll_f\":" + String(datos.roll_f, 2) + ",";
  payload += "\"pitch_f\":" + String(datos.pitch_f, 2) + ",";
  payload += "\"yaw_f\":" + String(datos.yaw_f, 2) + ",";
  payload += "\"ecg\":" + String(datos.ecg) + ",";
  payload += "\"roll_a\":" + String(datos.roll_a, 2) + ",";
  payload += "\"pitch_a\":" + String(datos.pitch_a, 2) + ",";
  payload += "\"yaw_a\":" + String(datos.yaw_a, 2);
  payload += "}";

  Serial.println(">>> Reenviando por MQTT (TLS/SSL) vía " + String(currentConnection == CONN_LTE ? "LTE" : "WiFi") + ":");
  Serial.println(payload);

  if (mqtt.publish(topicPublish, payload.c_str())) {
    Serial.println("MENSAJE RECIBIDO POR EL BROKER");
    return true;
  } else {
    Serial.println("Error de transmisión MQTT");
    mqttConnected = false;
    return false;
  }
}

// ==========================================
// SETUP
// ==========================================
void setup() {
  Serial.begin(115200);
  while (!Serial);
  
  Serial.println("=================================");
  Serial.println("GATEWAY LoRa -> MQTT (LTE/WiFi)");
  Serial.println("=================================");
  
  randomSeed(analogRead(0));
  
  // ----- INICIALIZAR LORA -----
  Serial.println("\n[LoRa] Inicializando...");
  SPI.begin(loraSCK, loraMISO, loraMOSI, loraNSS);
  LoRa.setPins(loraNSS, loraRST, loraDI0);

  if (!LoRa.begin(433E6)) {
    Serial.println("[LoRa] Fallo! Continuando solo con MQTT...");
  } else {
    LoRa.setSpreadingFactor(9);
    LoRa.setSignalBandwidth(125E3);
    LoRa.setCodingRate4(6);
    LoRa.setSyncWord(SyncWord);
    
    Serial.println("[LoRa] Listo Receptor");
    Serial.print("[LoRa] Mi direccion: 0x"); Serial.println(dir_local, HEX);
  }
  
  // ----- CONEXIÓN A INTERNET (LTE con fallback WiFi) -----
  Serial.println("\n[Internet] Estableciendo conexión...");
  if (!conectarInternet()) {
    Serial.println("[Internet] ADVERTENCIA: Modo solo LoRa (sin MQTT)");
  }
  
  Serial.println("\n=================================");
  Serial.println("Esperando frames LoRa...");
  Serial.println("=================================");
}

// ==========================================
// LOOP PRINCIPAL
// ==========================================
void loop() {
  // Mantener conexión MQTT activa si hay internet
  if (currentConnection != CONN_NONE) {
    mqtt.loop();
  } else {
    // Si no hay conexión, intentar reconectar periódicamente
    static unsigned long ultimoIntentoConexion = 0;
    if (millis() - ultimoIntentoConexion > 60000) { // Cada 60 segundos
      ultimoIntentoConexion = millis();
      conectarInternet();
    }
  }
  
  // Verificar recepción LoRa
  int packetSize = LoRa.parsePacket();
  
  if (packetSize >= 4) {
    byte bufferPaquete[packetSize];
    LoRa.readBytes(bufferPaquete, packetSize);
    
    int idx = 0;
    
    dir_envio  = bufferPaquete[idx++]; 
    dir_remite = bufferPaquete[idx++]; 
    paqRcb_ID  = bufferPaquete[idx++]; 
    byte len   = bufferPaquete[idx++];
    
    if (packetSize - 4 != len) {
      Serial.println("Error: Tamaño de paquete no coincide");
      return;
    }
    
    if (dir_envio != dir_local && dir_envio != 0xFF) {
      return; // No es para mí
    }
    
    if (len == sizeof(struct_message)) {
      
      struct_message cansatData;
      memcpy(&cansatData, &bufferPaquete[idx], len);
      
      // Mostrar datos recibidos por LoRa
      Serial.print("\n[LoRa] Recibido Frame VALIDO:");
      Serial.print("\n  De: 0x"); Serial.print(dir_remite, HEX);
      Serial.print("\n  Para: 0x"); Serial.print(dir_envio, HEX);
      Serial.print("\n  ID: "); Serial.print(paqRcb_ID);
      Serial.print("\n  roll_f = "); Serial.print(cansatData.roll_f);
      Serial.print("\n  pitch_f = "); Serial.print(cansatData.pitch_f);
      Serial.print("\n  yaw_f = "); Serial.print(cansatData.yaw_f);
      Serial.print("\n  ecg = "); Serial.print(cansatData.ecg);
      Serial.print("\n  roll_a = "); Serial.print(cansatData.roll_a);
      Serial.print("\n  pitch_a = "); Serial.print(cansatData.pitch_a);
      Serial.print("\n  yaw_a = "); Serial.print(cansatData.yaw_a);
      
      Serial.println();
      Serial.print("  RSSI ="); Serial.print(LoRa.packetRssi());
      Serial.print(" | SNR ="); Serial.println(LoRa.packetSnr(), 1);
      
      // REENVIAR POR MQTT (solo si hay conexión a internet)
      if (currentConnection != CONN_NONE) {
        Serial.println("\n[MQTT] Reenviando...");
        if (enviarMQTT(cansatData)) {
          Serial.println("[MQTT] Reenvío exitoso");
        } else {
          Serial.println("[MQTT] Error en reenvío");
        }
      } else {
        Serial.println("\n[ERROR] Sin conexión a internet, datos no enviados");
      }
      
      Serial.println("---------------------------------");
      
    } else {
      Serial.println("Error: Tamaño de payload incorrecto");
    }
  }
  
  delay(10); // Pequeña pausa para estabilidad
}

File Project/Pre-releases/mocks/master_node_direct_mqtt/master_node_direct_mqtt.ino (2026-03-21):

#include <WiFi.h>
#include <esp_now.h>
#include <PubSubClient.h>
#include <WiFiClientSecure.h>

// ==========================================
// CONFIGURACIÓN WIFI
// ==========================================
const char* ssid = "AsusE";
const char* wifi_password = "23011edpi";

// ==========================================
// CONFIGURACIÓN MQTT CON TLS/SSL
// ==========================================
const char* broker = "oc051111.ala.us-east-1.emqxsl.com";
const char* topicPublish = "test01";
const int port = 8883;
const char* mqtt_user = "edpi";
const char* mqtt_password = "edpi";

// CERTIFICADO CA
const char* ca_cert = \
"-----BEGIN CERTIFICATE-----\n" \
"MIIDjjCCAnagAwIBAgIQAzrx5qcRqaC7KGSxHQn65TANBgkqhkiG9w0BAQsFADBh\n" \
"MQswCQYDVQQGEwJVUzEVMBMGA1UEChMMRGlnaUNlcnQgSW5jMRkwFwYDVQQLExB3\n" \
"d3cuZGlnaWNlcnQuY29tMSAwHgYDVQQDExdEaWdpQ2VydCBHbG9iYWwgUm9vdCBH\n" \
"MjAeFw0xMzA4MDExMjAwMDBaFw0zODAxMTUxMjAwMDBaMGExCzAJBgNVBAYTAlVT\n" \
"MRUwEwYDVQQKEwxEaWdpQ2VydCBJbmMxGTAXBgNVBAsTEHd3dy5kaWdpY2VydC5j\n" \
"b20xIDAeBgNVBAMTF0RpZ2lDZXJ0IEdsb2JhbCBSb290IEcyMIIBIjANBgkqhkiG\n" \
"9w0BAQEFAAOCAQ8AMIIBCgKCAQEAuzfNNNx7a8myaJCtSnX/RrohCgiN9RlUyfuI\n" \
"2/Ou8jqJkTx65qsGGmvPrC3oXgkkRLpimn7Wo6h+4FR1IAWsULecYxpsMNzaHxmx\n" \
"1x7e/dfgy5SDN67sH0NO3Xss0r0upS/kqbitOtSZpLYl6ZtrAGCSYP9PIUkY92eQ\n" \
"q2EGnI/yuum06ZIya7XzV+hdG82MHauVBJVJ8zUtluNJbd134/tJS7SsVQepj5Wz\n" \
"tCO7TG1F8PapspUwtP1MVYwnSlcUfIKdzXOS0xZKBgyMUNGPHgm+F6HmIcr9g+UQ\n" \
"vIOlCsRnKPZzFBQ9RnbDhxSJITRNrw9FDKZJobq7nMWxM4MphQIDAQABo0IwQDAP\n" \
"BgNVHRMBAf8EBTADAQH/MA4GA1UdDwEB/wQEAwIBhjAdBgNVHQ4EFgQUTiJUIBiV\n" \
"5uNu5g/6+rkS7QYXjzkwDQYJKoZIhvcNAQELBQADggEBAGBnKJRvDkhj6zHd6mcY\n" \
"1Yl9PMWLSn/pvtsrF9+wX3N3KjITOYFnQoQj8kVnNeyIv/iPsGEMNKSuIEyExtv4\n" \
"NeF22d+mQrvHRAiGfzZ0JFrabA0UWTW98kndth/Jsw1HKj2ZL7tcu7XUIOGZX1NG\n" \
"Fdtom/DzMNU+MeKNhJ7jitralj41E6Vf8PlwUHBHQRFXGU7Aj64GxJUTFy8bJZ91\n" \
"8rGOmaFvE7FBcf6IKshPECBV1/MUReXgRPTqh5Uykw7+U0b6LJ3/iyK5S9kJRaTe\n" \
"pLiaWN0bfVKfjllDiIGknibVb63dDcY3fe0Dkhvld1927jyNxF1WW6LZZm6zNTfl\n" \
"MrY=\n" \
"-----END CERTIFICATE-----\n";

// ==========================================
// ESTRUCTURAS PARA CADA NODO
// ==========================================
typedef struct struct_message_arm {
    float roll_a;
    float pitch_a;
    float yaw_a;
    int ecg;
    int node_id;
} struct_message_arm;

typedef struct struct_message_forearm {
    float roll_f;
    float pitch_f;
    float yaw_f;
    int node_id;
} struct_message_forearm;

// Buffer para almacenar datos temporalmente
struct_message_arm ultimosDatosBrazo;
struct_message_forearm ultimosDatosAntebrazo;

bool brazoInicializado = false;
bool antebrazoInicializado = false;
bool datosPendientes = false;  // Flag para indicar que hay datos nuevos para enviar

unsigned long tiempoUltimoBrazo = 0;
unsigned long tiempoUltimoAntebrazo = 0;
const unsigned long TIMEOUT_MS = 5000;  // Aumentado a 5 segundos

// ==========================================
// VARIABLES MQTT
// ==========================================
WiFiClientSecure espClient;
PubSubClient client(espClient);
unsigned long lastMQTTSendTime = 0;
const long mqttInterval = 2000;

// ==========================================
// VARIABLES PARA ALTERNAR MODOS
// ==========================================
enum SystemMode {
    MODE_ESPNOW_RECEIVE,  // Modo recepción ESP-NOW
    MODE_WIFI_SEND        // Modo envío MQTT
};

SystemMode currentMode = MODE_ESPNOW_RECEIVE;
unsigned long modeStartTime = 0;
const unsigned long ESPNOW_RECEIVE_DURATION = 1000;  // 3 segundos escuchando ESP-NOW
const unsigned long WIFI_SEND_DURATION = 1000;       // 3 segundos para WiFi/MQTT

// ==========================================
// FUNCIONES WIFI Y MQTT
// ==========================================
void conectarWiFi() {
    Serial.print("Conectando WiFi...");
    WiFi.mode(WIFI_STA);
    WiFi.begin(ssid, wifi_password);
    
    int attempts = 0;
    while (WiFi.status() != WL_CONNECTED && attempts < 30) {
        delay(500);
        Serial.print(".");
        attempts++;
    }
    
    if (WiFi.status() == WL_CONNECTED) {
        Serial.println("\nWiFi conectado");
        Serial.print("IP: ");
        Serial.println(WiFi.localIP());
        Serial.print("Canal: ");
        Serial.println(WiFi.channel());
    } else {
        Serial.println("\nError conectando WiFi");
    }
}

void conectarMQTT() {
    espClient.setCACert(ca_cert);
    client.setServer(broker, port);
    
    int attempts = 0;
    while (!client.connected() && attempts < 5) {
        Serial.print("Conectando MQTT...");
        if (client.connect("ESP32_Master_Node", mqtt_user, mqtt_password)) {
            Serial.println("Conectado");
        } else {
            Serial.print("Error, rc=");
            Serial.print(client.state());
            Serial.println(" Reintentando...");
            delay(2000);
            attempts++;
        }
    }
}

void desconectarWiFi() {
    WiFi.disconnect(true);
    WiFi.mode(WIFI_OFF);
    Serial.println("WiFi desconectado");
}

void iniciarModoESPNOW() {
    // Apagar WiFi para liberar el módulo
    WiFi.mode(WIFI_OFF);
    delay(100);
    
    // Inicializar ESP-NOW
    WiFi.mode(WIFI_STA);
    if (esp_now_init() != ESP_OK) {
        Serial.println("Error inicializando ESP-NOW");
        return;
    }
    esp_now_register_recv_cb(OnDataRecv);
    
    Serial.println("Modo ESP-NOW: Escuchando datos...");
}

void detenerModoESPNOW() {
    esp_now_deinit();
    Serial.println("ESP-NOW detenido");
}
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

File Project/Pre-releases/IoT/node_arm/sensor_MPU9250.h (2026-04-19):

#ifndef SENSOR_MPU9250_H
#define SENSOR_MPU9250_H

#include <Arduino.h>
#include <Wire.h>
#include <math.h>

struct Orientation {
    float yaw;
    float pitch;
    float roll;
};

class MyMPU9250 {
private:
    const int SDA_PIN = 1;
    const int SCL_PIN = 0;
    const int MPU_ADDR = 0x68;

    const float ACCEL_SCALE = 16384.0;
    const float GYRO_SCALE = 131.0;

    const float GYRO_BIAS_X = -59.07;
    const float GYRO_BIAS_Y = -98.43;
    const float GYRO_BIAS_Z = 92.64;

    const float ACC_BIAS_X = 6331.23;
    const float ACC_BIAS_Y = -1842.82;
    const float ACC_BIAS_Z = 3214.87;

    // 🔹 NUEVO: umbral de zona muerta (ajustable)
    const float GYRO_DEADBAND = 0.1;

    int16_t axRaw, ayRaw, azRaw, gxRaw, gyRaw, gzRaw;

    float roll = 0, pitch = 0, yaw = 0;
    float rollOffset = 0, pitchOffset = 0, yawOffset = 0;

    bool calibrated = false;
    bool firstRead = true;

    unsigned long prevTime = 0;
    unsigned long calibrationStart = 0;

    float rollSum = 0, pitchSum = 0, yawSum = 0;
    int calibrationSamples = 0;

    void readMPU() {
        Wire.beginTransmission(MPU_ADDR);
        Wire.write(0x3B);
        Wire.endTransmission(false);
        Wire.requestFrom(MPU_ADDR, 14, true);

        axRaw = Wire.read() << 8 | Wire.read();
        ayRaw = Wire.read() << 8 | Wire.read();
        azRaw = Wire.read() << 8 | Wire.read();
        Wire.read(); Wire.read();
        gxRaw = Wire.read() << 8 | Wire.read();
        gyRaw = Wire.read() << 8 | Wire.read();
        gzRaw = Wire.read() << 8 | Wire.read();
    }

    float normalizeAngle(float angle) {
        while (angle > 180) angle -= 360;
        while (angle < -180) angle += 360;
        return angle;
    }

    // 🔹 NUEVO: deadband suave (evita saltos bruscos)
    float applyDeadband(float value, float threshold) {
        if (abs(value) < threshold) return 0;
        return value - (value > 0 ? threshold : -threshold);
    }

public:
    void begin() {
        Serial.println("Iniciando MPU9250...");

        Wire.begin(SDA_PIN, SCL_PIN);

        Wire.beginTransmission(MPU_ADDR);
        Wire.write(0x6B);
        Wire.write(0x00);
        Wire.endTransmission();

        delay(100);

        readMPU();

        float ax = (axRaw - ACC_BIAS_X) / ACCEL_SCALE;
        float ay = (ayRaw - ACC_BIAS_Y) / ACCEL_SCALE;
        float az = (azRaw - ACC_BIAS_Z) / ACCEL_SCALE;

        roll = atan2(ay, az) * 180.0 / PI;
        pitch = atan2(-ax, sqrt(ay * ay + az * az)) * 180.0 / PI;
        yaw = 0;

        prevTime = micros();
        calibrationStart = millis();

        firstRead = true;

        Serial.println("Calibrando 3 segundos...");
    }

    Orientation getData() {
        unsigned long now = micros();
        float dt = (now - prevTime) / 1000000.0;
        prevTime = now;

        if (dt <= 0 || dt > 0.5) dt = 0.01;

        readMPU();

        float gx = (gxRaw - GYRO_BIAS_X) / GYRO_SCALE;
        float gy = (gyRaw - GYRO_BIAS_Y) / GYRO_SCALE;
        float gz = (gzRaw - GYRO_BIAS_Z) / GYRO_SCALE;

        // 🔥 APLICACIÓN DEL DEADBAND (AQUÍ ESTÁ LA CLAVE)
        gx = applyDeadband(gx, GYRO_DEADBAND);
        gy = applyDeadband(gy, GYRO_DEADBAND);
        gz = applyDeadband(gz, GYRO_DEADBAND);

        float ax = (axRaw - ACC_BIAS_X) / ACCEL_SCALE;
        float ay = (ayRaw - ACC_BIAS_Y) / ACCEL_SCALE;
        float az = (azRaw - ACC_BIAS_Z) / ACCEL_SCALE;

        float accRoll = atan2(ay, az) * 180.0 / PI;
        float accPitch = atan2(-ax, sqrt(ay * ay + az * az)) * 180.0 / PI;

        if (firstRead) {
            roll = accRoll;
            pitch = accPitch;
            yaw = 0;
            firstRead = false;
        } else {
            // Filtro complementario (igual que tu versión)
            roll = normalizeAngle(0.96 * (roll + gx * dt) + 0.04 * accRoll);
            pitch = normalizeAngle(0.96 * (pitch + gy * dt) + 0.04 * accPitch);

            // Integración yaw (ahora con menos drift)
            yaw += gz * dt;
            yaw = normalizeAngle(yaw);
        }

        Orientation data;

        if (!calibrated) {
            rollSum += roll;
            pitchSum += pitch;
            yawSum += yaw;
            calibrationSamples++;

            if (millis() - calibrationStart > 3000) {
                rollOffset = rollSum / calibrationSamples;
                pitchOffset = pitchSum / calibrationSamples;
                yawOffset = yawSum / calibrationSamples;

                calibrated = true;
                Serial.println("Calibración completa");
            }

            data.roll = roll;
            data.pitch = pitch;
            data.yaw = yaw;

        } else {
            data.roll = roll - rollOffset;
            data.pitch = pitch - pitchOffset;
            data.yaw = yaw - yawOffset;
        }

        return data;
    }
};

#endif

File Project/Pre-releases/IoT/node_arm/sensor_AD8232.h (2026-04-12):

#ifndef SENSOR_AD8232_H
#define SENSOR_AD8232_H

#include <Arduino.h>

class MyAD8232 {
private:
    // Pines para AD8232
    const int PIN_ECG = 2;   // Salida analógica
    const int PIN_LOP = 3;   // Leads OFF detect - (detecta desconexión)
    const int PIN_LON = 5;   // Leads OFF detect + (antes era el 5)
    
    int lastECGValue;
    int minECG;
    int maxECG;
    
public:
    MyAD8232() : lastECGValue(0), minECG(0), maxECG(4095) {}
    
    void begin() {
        Serial.println("Iniciando AD8232 real...");
        
        pinMode(PIN_ECG, INPUT);
        pinMode(PIN_LOP, INPUT);
        pinMode(PIN_LON, INPUT);
        
        Serial.println("AD8232 listo - Sensor de ECG real");
    }
    
    int getECG() {
        // Leer señal ECG
        int ecg = analogRead(PIN_ECG);
        
        // Verificar desconexión de electrodos
        if (digitalRead(PIN_LOP) == HIGH || digitalRead(PIN_LON) == HIGH) {
            lastECGValue = 0;  // Señal 0 si están desconectados
        } else {
            lastECGValue = ecg;
        }
        
        return lastECGValue;
    }
    
    // Método adicional para verificar si los electrodos están conectados
    bool isLeadsOff() {
        return (digitalRead(PIN_LOP) == HIGH || digitalRead(PIN_LON) == HIGH);
    }
};

#endif

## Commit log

2026-02-23 refactor: SMS & LoRa comm
    [ESP32_LoRa_SX1278_Sender_Receiver.fzz]
2026-02-26 All tests completed
    [Breadboard-ESP32-FLEX-MPU-MAX - copia.fzz, Prototype-ESP32-FLEX-MPU-MAX - copia.fzz, Prototype-ESP32-FLEX-MPU-MAX.fzz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]
2026-03-01 wiring diagrams ended
    [Breadboard-ESP32-FLEX-MPU-MAX - copia.fzz, Prototype-ESP32-FLEX-MPU-MAX - copia.fzz, Prototype-ESP32-FLEX-MPU-MAX.fzz]
2026-03-03 Corrección No quedo
    [Case.FCStd, Case.blend, Prototype-ESP32-FLEX-MPU-MAX.fzz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]
2026-03-07 ahora si se solda este
    [Prototype-ESP32-FLEX-MPU-MAX-Conections.fzz, Prototype-ESP32-FLEX-MPU-MAX.fzz]
2026-03-12 new threejs test
    [Prototype-ESP32-FLEX-MPU-MAX-Conections.fzz, Prototype-ESP32-FLEX-MPU-MAX.fzz, _old_Prototype-ESP32-FLEX-MPU-MAX-Conections.fzz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]
2026-03-16 refactor: new directories distribution
    [1_Connections-Prototype-ESP32-FLEX-MPU-MAX.fzz, 2_Scheme-ESP32-FLEX-MPU-MAX.fzz, 3_ESP32_LoRa_SX1278_MasterNode.fzz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]
2026-03-19 Diagram completed
    [2_Scheme-ESP32-FLEX-MPU-MAX.fzz, Liligo7070g_LoRa_SX1278_Gateway.fzz]
2026-04-09 First Case 3D Model
    [Case.FCStd, Case.blend, SesnsorsCase.f3d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]
2026-04-11 Case 3D Model
    [BottomCase.stl, BottomCaseLiligo.stl, BottomCaseLoRa.stl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]
2026-04-12 Docker implementation and path project fixed
    [1_Connections-Prototype-ESP32-FLEX-MPU-MAX.fzz, 2_Scheme-ESP32-FLEX-MPU-MAX.fzz, 3_ESP32_LoRa_SX1278_MasterNode.fzz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]
2026-04-15 New fixes
    [1_Connections-Prototype-ESP32-MPU9250-AD8232.fzz, 2_Scheme-ESP32-FLEX-MPU9250-AD8232.fzz]
2026-04-19 Calibrate MPU
2026-04-28 Fix: Yaw_f
2026-09-01 view 3d
    [PrototypeView.blend]
2026-09-18 Page preparation
    [PrototypeView.blend]
